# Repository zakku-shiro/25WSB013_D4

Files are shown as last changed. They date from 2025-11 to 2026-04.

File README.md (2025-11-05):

# project-pied-piper

This project is for the 25WSB013 - Project Design and Management module at Loughborough University, tackling specifically the "Pied Piper" challenge.

## Useful Links

### [Generic Project Information](https://learn.lboro.ac.uk/mod/forum/discuss.php?d=498549)

### [Pied Piper Specific Information](https://learn.lboro.ac.uk/mod/forum/discuss.php?d=498557)

### [RobotShop Rover Link](https://uk.robotshop.com/products/dfrobotshop-rover-tracked-robot-basic-kit)

### [Markdown Guide](https://www.markdownguide.org/basic-syntax/)

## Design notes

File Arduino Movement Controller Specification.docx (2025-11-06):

# Arduino Movement Controller Specification

# Important Definitions and Values

## Servo Motor Pinouts

PIN_MOTOR_1_SPEED (0x06)

Type: ANALOGUE

Values: 0-255, (0x00-0xFF)

Functionality: Controls the speed of the leftmost motor, with 0 being stationary and 255 being full speed.

PIN_MOTOR_1_DIRECTION (0x08)

Type: DIGITAL

Values: LOW|HIGH, (0|1)

Functionality: Controls the direction of the leftmost motor, with LOW being forward and HIGH being reverse.

PIN_MOTOR_2_SPEED (0x05)

Type: ANALOGUE

Values: 0-255, (0x00-0xFF)

Functionality: Controls the speed of the leftmost motor, with 0 being stationary and 255 being full speed.

PIN_MOTOR_2_DIRECTION (0x07)

Type: DIGITAL

Values: LOW|HIGH, (0|1)

Functionality: Controls the direction of the leftmost motor, with LOW being forward and HIGH being reverse.

## Helper Values

MOTOR_FORWARD (0x00, 0)

MOTOR_REVERSE (0x01, 1)

MOTOR_OFF_SPEED (0x00, 0)

MOTOR_MIN_SPEED (0x01, 1)

MOTOR_HALF_SPEED (0x7F, 127)

MOTOR_MAX_SPEED (0xFF, 255)

# Functions and Uses

## `moveForward`

## `moveReverse`

## `turnLeft`

## `turnRight`

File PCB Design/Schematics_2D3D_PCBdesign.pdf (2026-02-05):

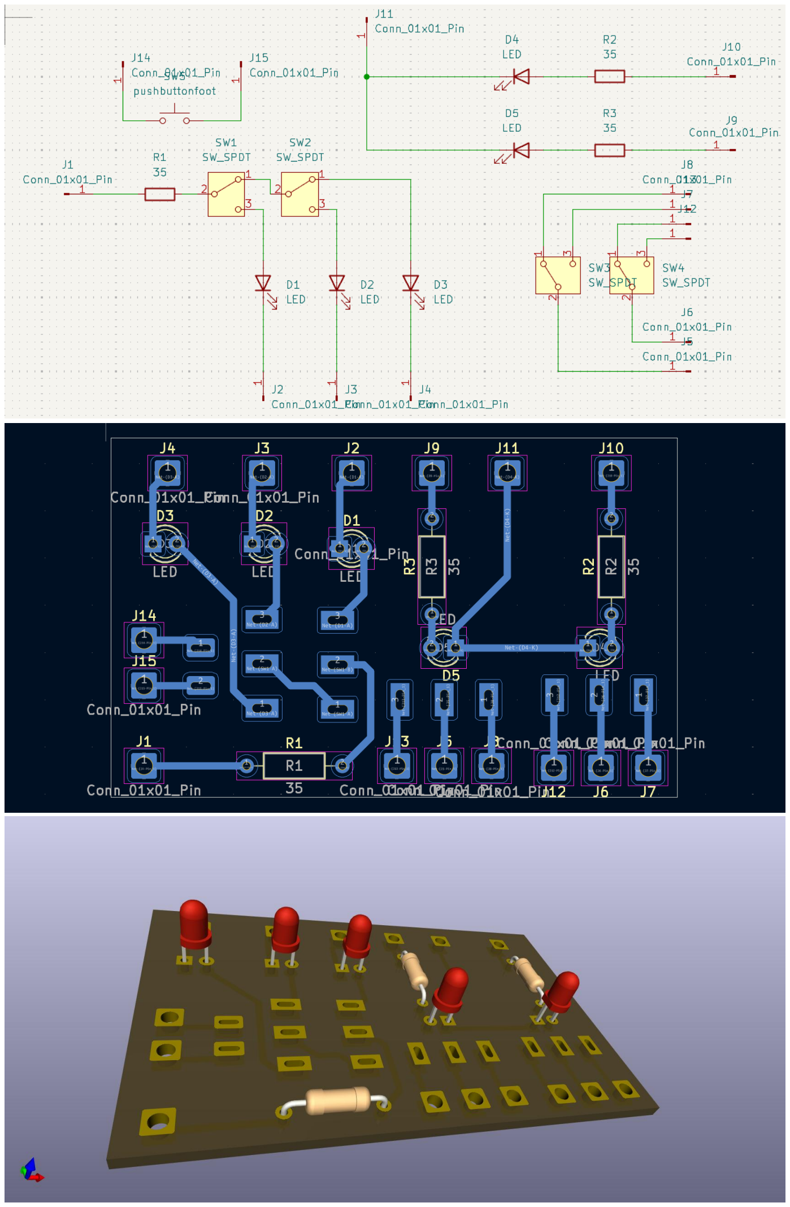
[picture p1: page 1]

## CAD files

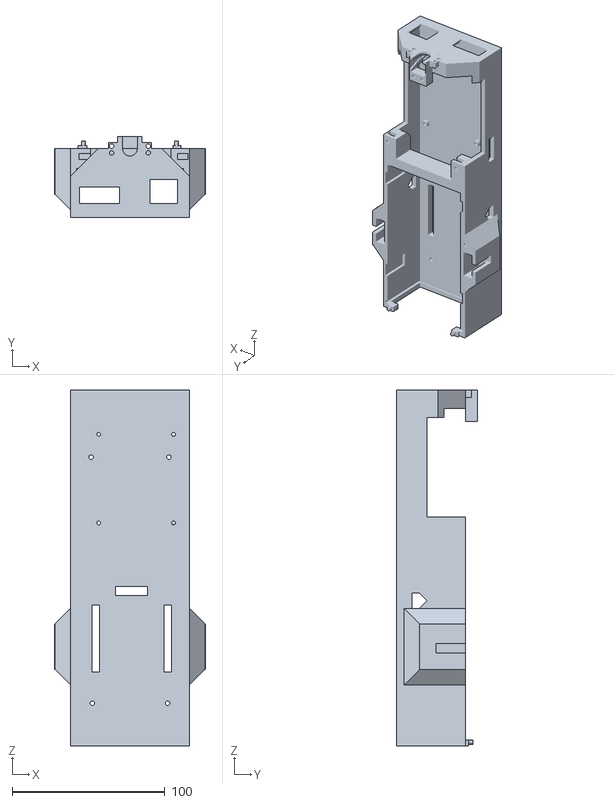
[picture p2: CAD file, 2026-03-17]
3d models and prints/main body new.stl
99.0 x 53.0 x 233.0

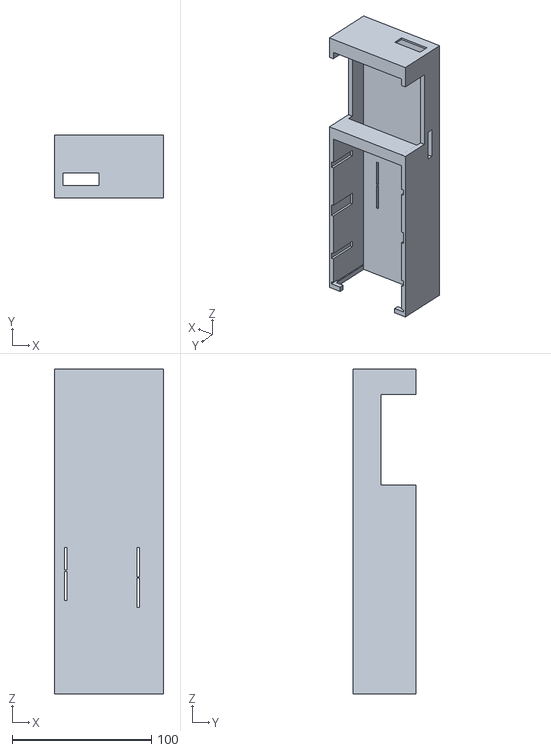
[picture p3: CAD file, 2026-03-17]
3d models and prints/main body.stl
78.0 x 45.0 x 233.0

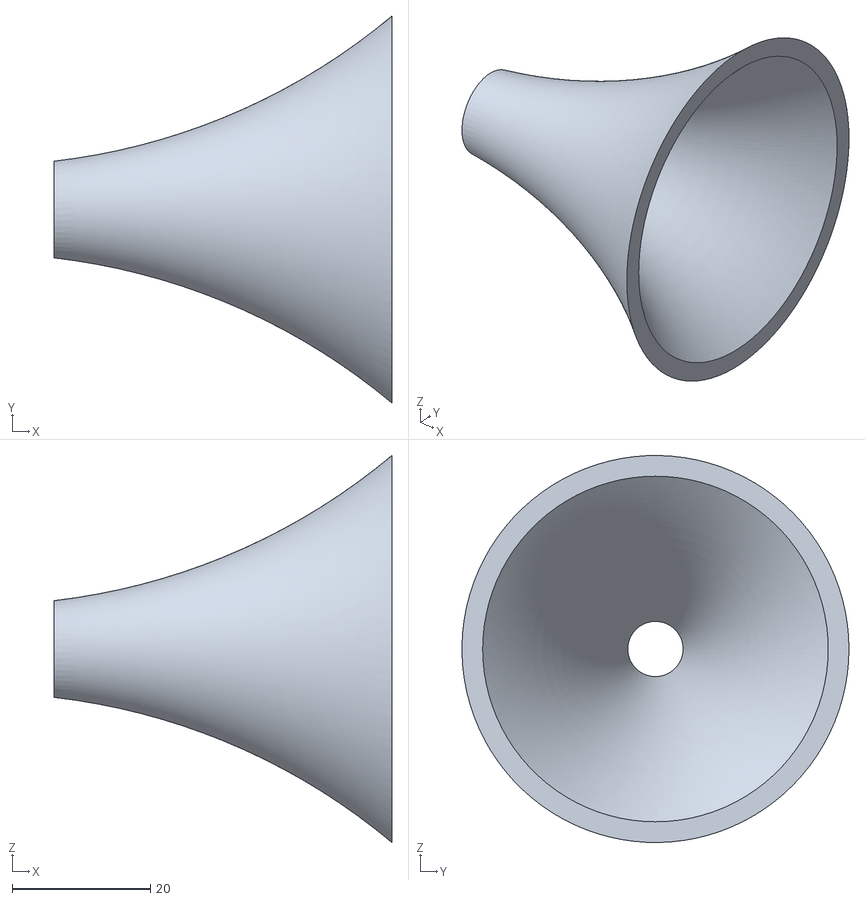
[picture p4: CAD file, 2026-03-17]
3d models and prints/Mic cone exp3.stl
48.9 x 56.0 x 56.0

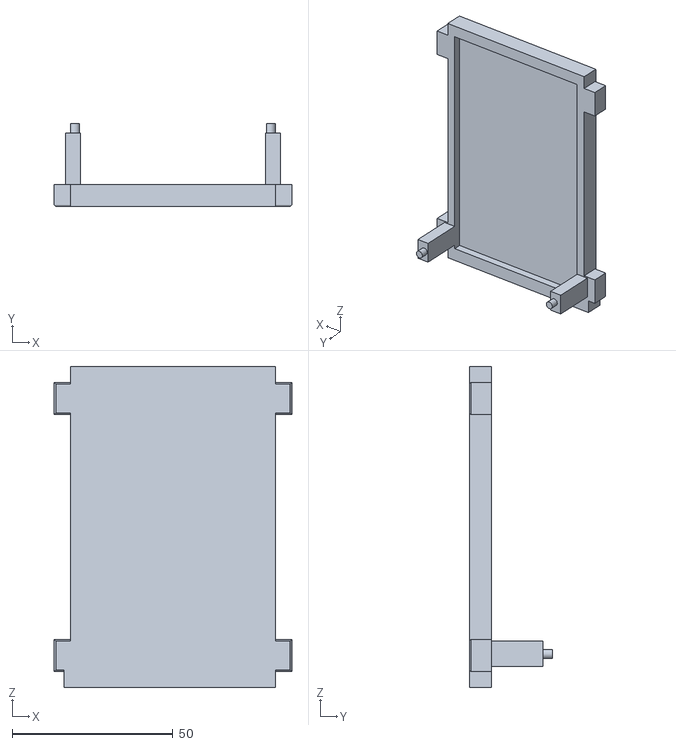
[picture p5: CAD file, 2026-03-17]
3d models and prints/battery mounting.stl
74.0 x 26.0 x 100.0

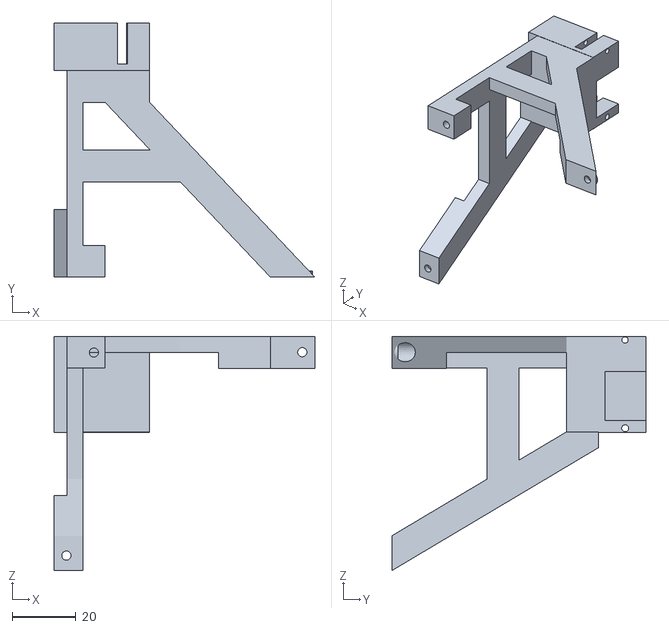
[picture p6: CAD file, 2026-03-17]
3d models and prints/cam stand.stl
82.1 x 80.0 x 73.7

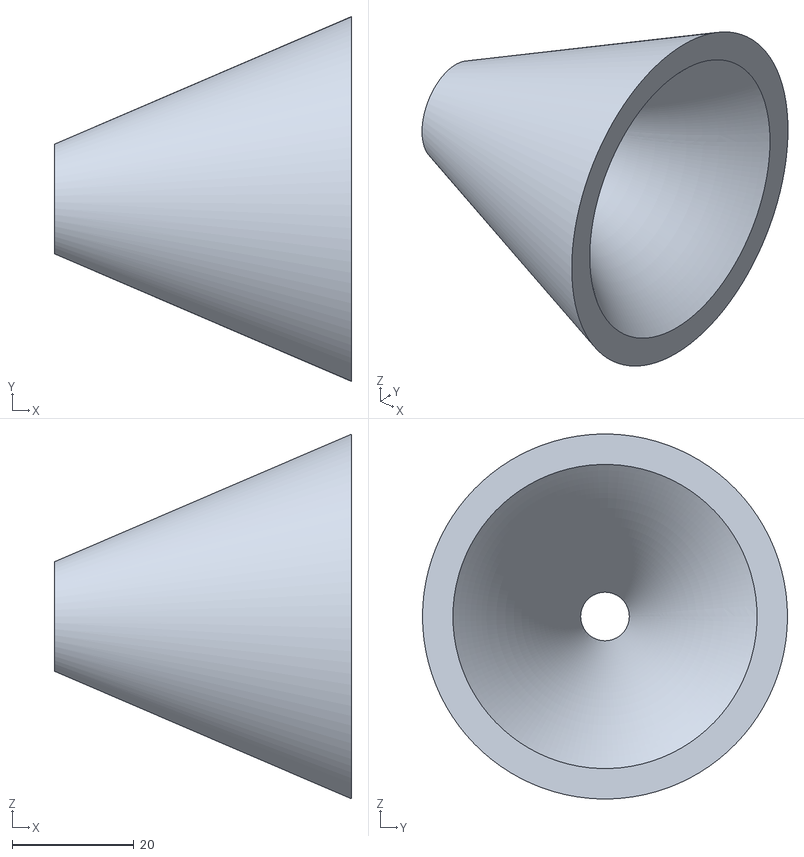
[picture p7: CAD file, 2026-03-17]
3d models and prints/Mic cone exp2.stl
48.9 x 60.0 x 60.0

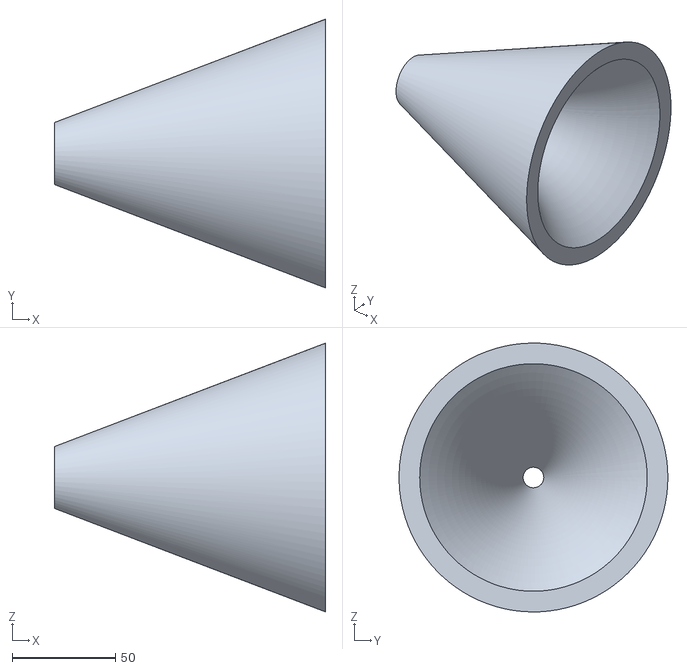
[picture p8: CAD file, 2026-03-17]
3d models and prints/Mic cone exp1.stl
131.0 x 130.0 x 130.0

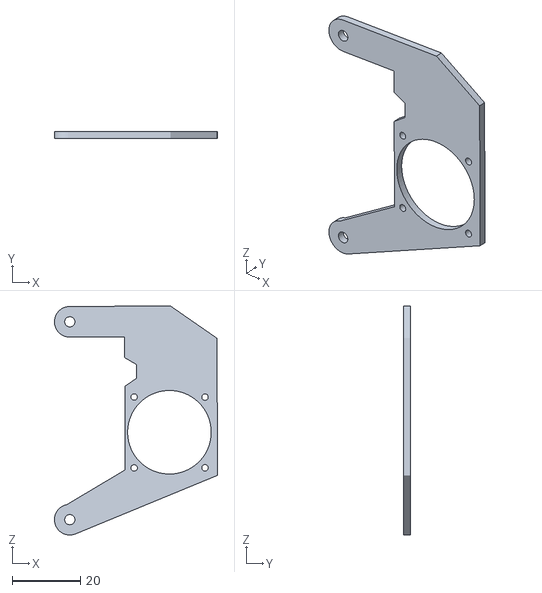
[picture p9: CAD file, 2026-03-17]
3d models and prints/fan mount.stl
47.8 x 2.00 x 67.1

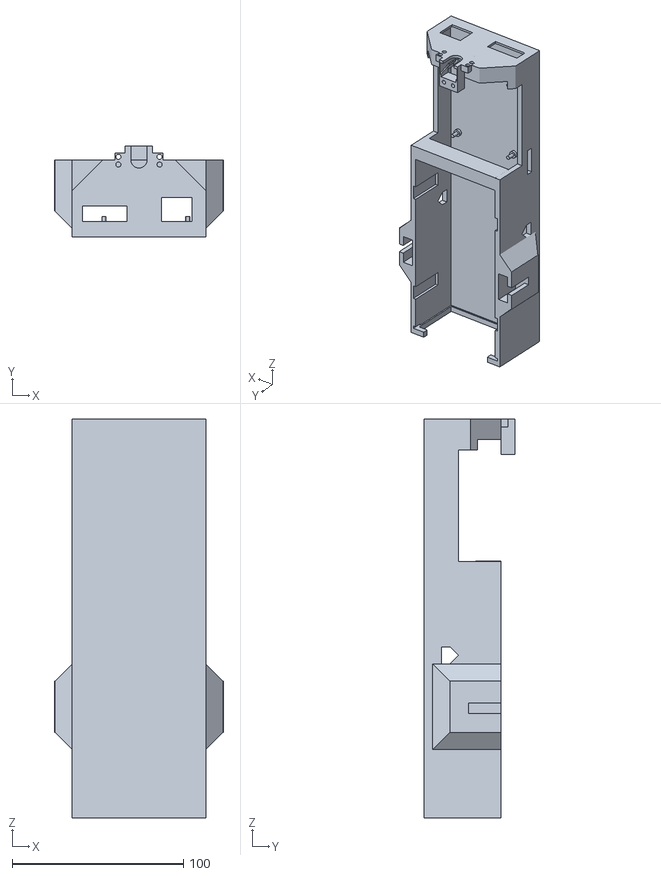
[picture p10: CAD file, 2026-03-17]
3d models and prints/body w front mic housing.stl
99.0 x 53.0 x 233.0

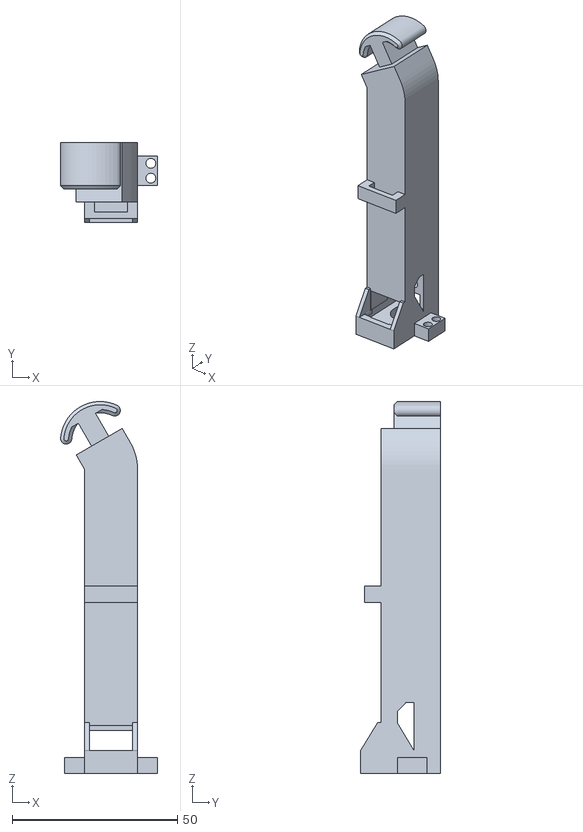
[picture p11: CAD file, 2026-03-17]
3d models and prints/mic arm.stl
29.3 x 24.1 x 112.5

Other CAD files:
3d models and prints/main body + fan mount.gcode.3mf
3d models and prints/main body.gcode.3mf
3d models and prints/tractric cone w attachment.gcode.3mf
3d models and prints/mic cone 1.gcode.3mf
3d models and prints/Join test.gcode.3mf
3d models and prints/camera bits.gcode.3mf
3d models and prints/Tractrix cone1.gcode.3mf
3d models and prints/pcb cover plate.gcode.3mf
3d models and prints/Mic cone exp3.gcode.3mf
3d models and prints/Tractrix cone1.stl
3d models and prints/battery mount.gcode.3mf
3d models and prints/cam mount.stl
3d models and prints/cam stand.gcode.3mf
3d models and prints/joint test1.stl
3d models and prints/joint test2.stl
3d models and prints/main body (2).stl
3d models and prints/mic arm (2).stl
3d models and prints/mic arm and cone1.gcode.3mf
3d models and prints/mic arm and cone2.gcode.3mf
3d models and prints/mic arm.gcode.3mf
3d models and prints/mic cone 1.3mf
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

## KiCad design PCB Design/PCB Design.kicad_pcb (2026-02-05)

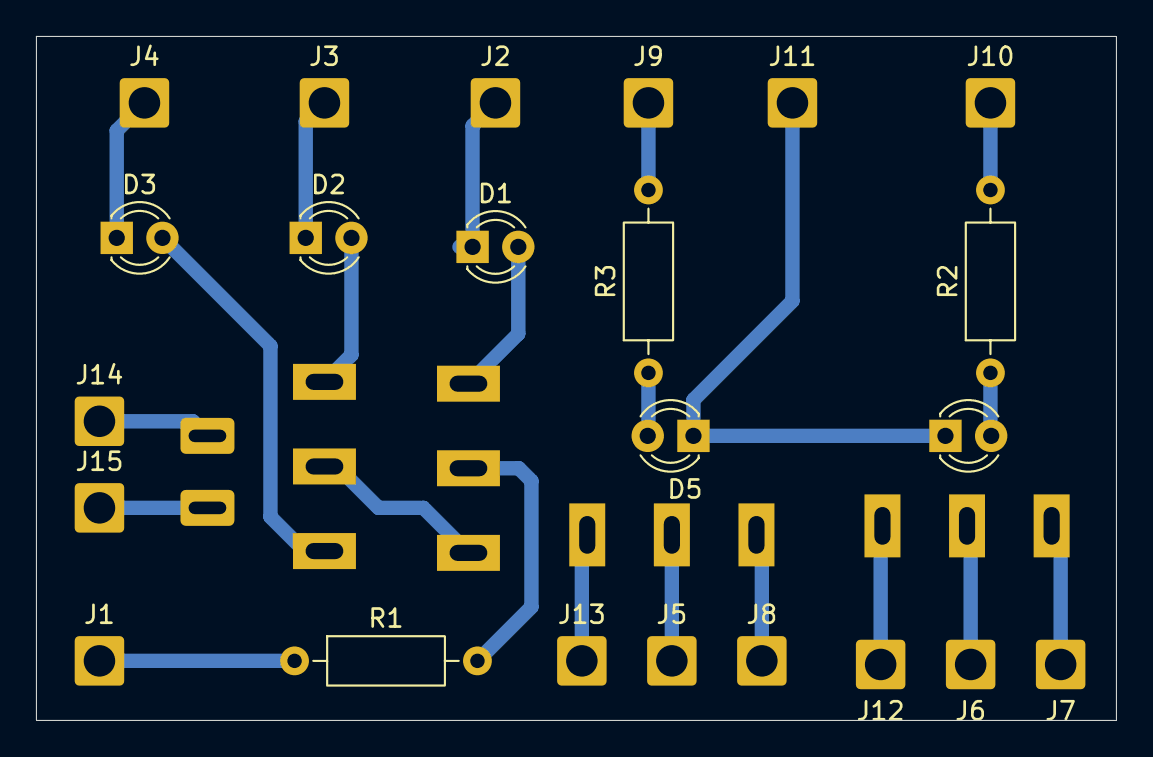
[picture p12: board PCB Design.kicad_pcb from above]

Board: 2 copper layers, 60.0 x 38.0 mm, 28 parts (0 on the bottom side), 22 nets.

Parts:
D1, D2, D3, D4, D5: LED; LED_D3.0mm
J1, J2, J3, J4, J5, J6, J7, J8, J9, J10, J11, J12, J13, J14, J15: Conn_01x01_Pin; SolderWire-1sqmm_1x01_D1.4mm_OD2.7mm
R1, R2, R3: 35; R_Axial_DIN0207_L6.3mm_D2.5mm_P10.16mm_Horizontal
SW1, SW2, SW3, SW4: SW_SPDT
SW5: pushbuttonfoot; Untitled

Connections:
unnamed: D1.2 (A), SW1.3 (C)
unnamed: D1.1 (K), J2.1
unnamed: D2.2 (A), SW2.3 (C)
unnamed: D2.1 (K), J3.1
unnamed: D3.2 (A), SW2.1 (A)
unnamed: D3.1 (K), J4.1
unnamed: D4.2 (A), R2.1
unnamed: D4.1 (K), D5.1 (K), J11.1
unnamed: D5.2 (A), R3.1
unnamed: J1.1, R1.1
unnamed: J5.1, SW3.2 (B)
unnamed: J6.1, SW4.2 (B)
unnamed: J7.1, SW4.1 (A)
unnamed: J8.1, SW3.1 (A)
unnamed: J9.1, R3.2
unnamed: J10.1, R2.2
unnamed: J12.1, SW4.3 (C)
unnamed: J13.1, SW3.3 (C)
unnamed: J14.1, SW5.1
unnamed: J15.1, SW5.2
unnamed: SW1.1 (A), SW2.2 (B)
unnamed: R1.2, SW1.2 (B)

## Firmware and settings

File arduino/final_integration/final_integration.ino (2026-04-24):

// Movement Definitions
#define PIN_MOTOR_1_SPEED 0x06
#define PIN_MOTOR_1_DIRECTION 0x08
#define PIN_MOTOR_2_SPEED 0x05
#define PIN_MOTOR_2_DIRECTION 0x07
// US Sensor Defs
#define US_TRIG_PIN 0x09
#define US_ECHO_PIN 0x0A
#define US_SEND_RATE_MS 250

#define MOTOR_FORWARD LOW
#define MOTOR_REVERSE HIGH

#define MOTOR_MAX_SPEED 255

// Comms Definitions
#define BAUD_RATE 500000
#define SYNC1 0xBE
#define SYNC2 0xEF
#define PACKET_BUFFER_SIZE 32

#define MOVE_PACKET_LENGTH 4
#define LED_PACKET_LENGTH 2

// Control Pins
#define LED_DEMO_ENABLED 0x0B
#define LED_MODE_SELECT  0x0C
#define LED_STATUS 0x02
#define DEMO_ENABLED_SWITCH 0x03
#define MODE_SELECT_SWITCH 0x04

enum {
  SIG_PING = 0,
  SIG_ERROR,
  SIG_ACKNOWLEDGE,
  SIG_SOUND_DATA,
  SIG_LED_COMMAND,
  SIG_MOVE_COMMAND,
  SIG_ULTRASONIC_DATA,
  SIG_SWITCH_DATA
};
static bool g_HasBeenAcknowledged = false;

// Watchdog Configs
unsigned long g_lastCommandTime = 0;
#define COMMAND_TIMEOUT_MS 1000

// US Controls
unsigned long g_lastUltrasonicPacketTime = 0;

// LED Controls
enum {
  OFF = 0,
  ON,
  SLOW_BLINK,
  FAST_BLINK
};  // LED Modes
#define BLINKING_TIME 200

bool g_isOnboardLEDOn = false,
     g_isOnboardLEDBlinking = false,
     g_isStatusLEDOn = false;
unsigned long g_OnboardLEDTargetTime = 0,
              g_StatusLEDTargetTime = 0;
uint8_t g_CurrentStatusLEDMode = OFF;

void setLeftMotorSpeed(uint8_t speed) {
  analogWrite(PIN_MOTOR_1_SPEED, speed);
}

void setLeftMotorDirection(uint8_t direction) {
  digitalWrite(PIN_MOTOR_1_DIRECTION, direction);
}

void setRightMotorSpeed(uint8_t speed) {
  analogWrite(PIN_MOTOR_2_SPEED, speed);
}

void setRightMotorDirection(uint8_t direction) {
  digitalWrite(PIN_MOTOR_2_DIRECTION, direction);
}

float getDistanceCm() {
  digitalWrite(US_TRIG_PIN, LOW);
  delayMicroseconds(2);
  digitalWrite(US_TRIG_PIN, HIGH);
  delayMicroseconds(10);
  digitalWrite(US_TRIG_PIN, LOW);

  long duration = pulseIn(US_ECHO_PIN, HIGH, 15000);

  if (duration == 0) {
    return 0;
  }
  
  // Formula for distance
  float distance = duration * 0.0343 / 2.0;
  return distance;
}

/*
  Packet Format:
  | SYNC1 | SYNC2 | TYPE | LEN | PAYLOAD | CRC |
*/
void parseSerial() {
  static uint8_t decodeState = 0;
  static uint8_t msgType;
  static uint8_t length;
  static uint8_t buffer[PACKET_BUFFER_SIZE];
  static uint8_t index;
  static uint8_t crc;

  enum {
    WAIT_SYNC1,
    WAIT_SYNC2,
    WAIT_TYPE,
    WAIT_LEN,
    WAIT_PAYLOAD,
    WAIT_CRC
  };

  while (Serial.available()) {
    uint8_t incomingByte = Serial.read();

    switch (decodeState) {
      case WAIT_SYNC1:
        if (incomingByte == SYNC1) decodeState = WAIT_SYNC2;
        break;

      case WAIT_SYNC2:
        if (incomingByte == SYNC2) decodeState = WAIT_TYPE;
        else decodeState = WAIT_SYNC1;
        break;

      case WAIT_TYPE:
        msgType = incomingByte;
        crc = incomingByte;
        decodeState = WAIT_LEN;
        break;

      case WAIT_LEN:
          length = incomingByte;
          if (length > PACKET_BUFFER_SIZE) { 
            decodeState = WAIT_SYNC1; 
            break;
          }
          crc ^= incomingByte;
          index = 0;
          decodeState = (length == 0) ? WAIT_CRC : WAIT_PAYLOAD;
          break;

      case WAIT_PAYLOAD:
        buffer[index++] = incomingByte;
        crc ^= incomingByte;

        if (index >= length)
          decodeState = WAIT_CRC;
        break;

      case WAIT_CRC:
        if (crc == incomingByte)
          handlePacket(msgType, buffer, length);

        decodeState = WAIT_SYNC1;
        break;
    }
  }
}

void handlePacket(uint8_t msg_type, uint8_t *data, uint8_t length) {
  bool invalidPacketLength = false;
  // Update watchdog timer
  g_lastCommandTime = millis();

  switch (msg_type) {
    case SIG_PING:
      sendPacket(SIG_ACKNOWLEDGE, 0, 0);
      return;

    case SIG_ACKNOWLEDGE:
      g_HasBeenAcknowledged = true;
      return;

    case SIG_LED_COMMAND: {
      if (length != LED_PACKET_LENGTH) {
        invalidPacketLength = true;
        break;
      }

      uint8_t pinIndex = data[0];
      uint8_t newStatus = data[1];

      switch (pinIndex) {
        case LED_DEMO_ENABLED:
        case LED_MODE_SELECT:
          digitalWrite(pinIndex, (newStatus == ON) ? HIGH : LOW);
          break;
        case LED_STATUS:
          g_CurrentStatusLEDMode = newStatus;
          break;
        default:
          break;
      }
      break;
    }

    case SIG_MOVE_COMMAND: {
      if (length != MOVE_PACKET_LENGTH) {
        invalidPacketLength = true;
        break;
      }

      setLeftMotorDirection(data[0] ? MOTOR_REVERSE : MOTOR_FORWARD);
      setRightMotorDirection(data[2] ? MOTOR_REVERSE : MOTOR_FORWARD);
      setLeftMotorSpeed((uint8_t)data[1]);
      setRightMotorSpeed((uint8_t)data[3]);

      break;
    }

    default: {
      uint8_t err[3] = {5, msg_type, length};
      sendPacket(SIG_ERROR, (uint8_t*)&err, 3);
      return;
    }
  }

  if (invalidPacketLength) {
    uint8_t err = 1;
    sendPacket(SIG_ERROR, &err, 1);
  } else {
    sendPacket(SIG_ACKNOWLEDGE, 0, 0);
  }
}

/*
    Packet Sender
*/
void sendPacket(uint8_t msgType, uint8_t *payload, uint8_t length) {
  if (Serial.availableForWrite() < (length + 5))
    return;

  uint8_t crc = msgType ^ length;

  Serial.write(SYNC1);
  Serial.write(SYNC2);
  Serial.write(msgType);
  Serial.write(length);

  for (uint8_t i = 0; i < length; i++) {
    Serial.write(payload[i]);
    crc ^= payload[i];
  }

  Serial.write(crc);
}

#define MIC_COUNT 3 // number of analog inputs
volatile uint16_t anaValue[MIC_COUNT];  // to store results (10-bit ADC fits in uint16_t)
volatile bool isFrameReady = false;

// ADC Interrupt Service Routine - fires when a conversion is complete
ISR(ADC_vect) {
  static uint8_t i = 0;

  anaValue[i] = ADC;
  i++;

  if (i >= MIC_COUNT) {
    i = 0;
    isFrameReady = true;
  }

  ADMUX = 0x40 | i;
  ADCSRA |= (1 << ADSC);
}

void setup() {
  pinMode(PIN_MOTOR_1_SPEED, OUTPUT);
  pinMode(PIN_MOTOR_1_DIRECTION, OUTPUT);
  pinMode(PIN_MOTOR_2_SPEED, OUTPUT);
  pinMode(PIN_MOTOR_2_DIRECTION, OUTPUT);
  pinMode(US_TRIG_PIN, OUTPUT);
  pinMode(US_ECHO_PIN, INPUT);
  pinMode(LED_BUILTIN, OUTPUT);
  pinMode(LED_MODE_SELECT, OUTPUT);
  pinMode(LED_DEMO_ENABLED, OUTPUT);
  pinMode(LED_STATUS, OUTPUT);
  pinMode(DEMO_ENABLED_SWITCH, INPUT_PULLUP);
  pinMode(MODE_SELECT_SWITCH, INPUT_PULLUP);

  // Zero Movement
  setLeftMotorSpeed(0);
  setRightMotorSpeed(0);
  
  /* Sound Setup*/
  // ADMUX: Set the reference voltage (AVCC) and select the first input A0 (0)
  ADMUX = 0x40; //| 0;

  ADCSRA |= (1 << ADIE);  //enable ADC Interrupt (ADIE)
  ADCSRA |= (1 << ADEN);  // enable ADC (ADEN)
  ADCSRA |= (1 << ADSC);  // start the first ADC conversion (ADSC)

  Serial.begin(BAUD_RATE);
  uint8_t counter = 0;
  while (!Serial) {
    digitalWrite(LED_BUILTIN, counter++ % 2);
  }

  // Read Switch States
  uint8_t switchStates[2] = {digitalRead(DEMO_ENABLED_SWITCH), digitalRead(MODE_SELECT_SWITCH)};
  sendPacket(SIG_SWITCH_DATA, (uint8_t*)&switchStates, 2);
  digitalWrite(LED_DEMO_ENABLED, switchStates[0]);
  digitalWrite(LED_MODE_SELECT, switchStates[1]);

  while (!g_HasBeenAcknowledged) {
    parseSerial();
  }
}

void loop() {
  parseSerial();

  // Watchdog safety stop
  if (millis() - g_lastCommandTime > COMMAND_TIMEOUT_MS && g_lastCommandTime != 0) {
    setLeftMotorSpeed(0);
    setRightMotorSpeed(0);
    setLeftMotorDirection(MOTOR_FORWARD);
    setRightMotorDirection(MOTOR_FORWARD);
  }

  // Ultrasonic Data Sending
  if (millis() - g_lastUltrasonicPacketTime > US_SEND_RATE_MS) {
    float distance = getDistanceCm();
    sendPacket(SIG_ULTRASONIC_DATA, (uint8_t*)&distance, sizeof(float));
    g_lastUltrasonicPacketTime = millis();
  }

  // Microphone Data Sending
  uint8_t packed_mic_data[4];
  if (isFrameReady) {
    isFrameReady = false;
    //removes end 2 of mic 1
    packed_mic_data[0] = (anaValue[0] >> 2) & 0xFF;
    //last 2 values of m1 shifted left 6, removes end half of m2
    packed_mic_data[1] = ((anaValue[0] & 0x03) << 6) | ((anaValue[1] >> 4) & 0x3F);
    //moves end half of m2 4 bits left, only keeps first 2 bits of m3 as last 2 bits
    packed_mic_data[2] = ((anaValue[1] & 0x0F) << 4) | ((anaValue[2] >> 6) & 0x0F);
    //rest of m3
    packed_mic_data[3] = (anaValue[2] & 0x3F);

    sendPacket(SIG_SOUND_DATA, (uint8_t*)&packed_mic_data, 4);
  }

  // LED Blink Handler - Horrific
  if (g_isOnboardLEDBlinking) {
    if (millis() >= g_OnboardLEDTargetTime) {
      if (g_isOnboardLEDOn) {
        digitalWrite(LED_BUILTIN, LOW);
        g_isOnboardLEDOn = false;
      } else {
        digitalWrite(LED_BUILTIN, HIGH);
        g_isOnboardLEDOn = true;
      }
      g_OnboardLEDTargetTime = millis() + BLINKING_TIME;
    }
  }

  switch (g_CurrentStatusLEDMode) {
    default:
    case OFF:
      if (g_isStatusLEDOn != false) {
        digitalWrite(LED_STATUS, LOW);
        g_isStatusLEDOn = false;
      }
      break;
    case ON:
      if (g_isStatusLEDOn != true) {
        digitalWrite(LED_STATUS, HIGH);
        g_isStatusLEDOn = true;
      }
      break;
    case SLOW_BLINK:
      if (millis() >= g_StatusLEDTargetTime) {
        g_isStatusLEDOn = !g_isStatusLEDOn;
        digitalWrite(LED_STATUS, g_isStatusLEDOn);
        g_StatusLEDTargetTime = millis() + BLINKING_TIME;
      }
      break;
    case FAST_BLINK:
      if (millis() >= g_StatusLEDTargetTime) {
        g_isStatusLEDOn = !g_isStatusLEDOn;
        digitalWrite(LED_STATUS, g_isStatusLEDOn);
        g_StatusLEDTargetTime = millis() + BLINKING_TIME / 2;
      }
      break;
  }
}

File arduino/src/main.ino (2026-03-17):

#define PIN_MOTOR_1_SPEED 0x06  // ANALOGUE,  0-255,    Left Motor Speed Control
#define PIN_MOTOR_1_DIRECTION \
  0x08  // DIGITAL,   LOW/HIGH, Left Motor Direction Control
#define PIN_MOTOR_2_SPEED \
  0x05  // ANALOGUE,  0-255,    Right Motor Speed Control
#define PIN_MOTOR_2_DIRECTION \
  0x07  // DIGITAL, LOW/HIGH, Right Motor Direction Control
#define MOTOR_FORWARD LOW
#define MOTOR_REVERSE HIGH
#define MOTOR_OFF_SPEED 0
#define MOTOR_MIN_SPEED 1
#define MOTOR_HALF_SPEED 127
#define MOTOR_MAX_SPEED 255
#define BAUD_RATE 500000

#include <Arduino.h>
#include <pins_arduino.h>
#include <stddef.h>

void setLeftMotorSpeed(uint8_t motor_speed) {
  Serial.print("Set Left Motor Speed: ");
  Serial.println(motor_speed);
  analogWrite(PIN_MOTOR_1_SPEED, motor_speed);
}

void setRightMotorSpeed(uint8_t motor_speed) {
  Serial.print("Set Right Motor Speed: ");
  Serial.println(motor_speed);
  analogWrite(PIN_MOTOR_2_SPEED, motor_speed);
}

void setMotorSpeed(uint8_t motor_speed) {
  setLeftMotorSpeed(motor_speed);
  setRightMotorSpeed(motor_speed);
}

void moveForward() {
  Serial.println("Change Direction: Forward");
  // Set both motors forward
  digitalWrite(PIN_MOTOR_1_DIRECTION, MOTOR_FORWARD);
  digitalWrite(PIN_MOTOR_2_DIRECTION, MOTOR_FORWARD);
}

void moveForward(size_t delay_ms) {
  moveForward();
  delay(delay_ms);
}

void moveReverse() {
  Serial.println("Change Direction: Reverse");
  // Set both motors in reverse
  digitalWrite(PIN_MOTOR_1_DIRECTION, MOTOR_REVERSE);
  digitalWrite(PIN_MOTOR_2_DIRECTION, MOTOR_REVERSE);
}

void moveReverse(size_t delay_ms) {
  moveReverse();
  delay(delay_ms);
}

void turnLeft() {
  Serial.println("Change Direction: Left");
  // Set motor directions
  digitalWrite(PIN_MOTOR_1_DIRECTION, MOTOR_REVERSE);
  digitalWrite(PIN_MOTOR_2_DIRECTION, MOTOR_FORWARD);
}

void turnLeft(size_t delay_ms) {
  turnLeft();
  delay(delay_ms);
}

void turnRight() {
  Serial.println("Change Direction: Right");
  // Set motor directions
  digitalWrite(PIN_MOTOR_1_DIRECTION, MOTOR_FORWARD);
  digitalWrite(PIN_MOTOR_2_DIRECTION, MOTOR_REVERSE);
}

void turnRight(size_t delay_ms) {
  turnRight();
  delay(delay_ms);
}

void stopMotors() {
  Serial.println("Stopped!");
  analogWrite(PIN_MOTOR_1_SPEED, MOTOR_OFF_SPEED);
  analogWrite(PIN_MOTOR_2_SPEED, MOTOR_OFF_SPEED);
}

void setup() {
  Serial.begin(BAUD_RATE);
  Serial.println("Serial Initialized");
  // GPIO Setup
  for (uint8_t i = 5; i <= 8; i++) {
    Serial.print("Set Pin #");
    Serial.print(i);
    Serial.println(": OUTPUT");
    pinMode(i, OUTPUT);
  }
  Serial.println("GPIO Initialized");

  setMotorSpeed(MOTOR_MAX_SPEED);
}

void loop() {
  turnRight(4000);
  turnLeft(4000);
  moveForward(1000);
  turnRight(1000);
  moveForward(5000);
  turnRight(1000);
  moveForward(5000);
  turnRight(1000);
  moveForward(10000);
  turnRight(1000);
  moveForward(5000);
  turnRight(1000);
  moveForward(5000);
  turnRight(1000);
  moveForward(1000);
  turnRight(2000);
}

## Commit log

2025-11-05 Add RobotRover sample code
2025-11-06 Create Platform IO Project for Arduino
2025-11-14 Initial Commits for PCB
    [PCB Design.kicad_pcb, PCB Design.kicad_sch]
2025-11-15 intial circuit implementation
    [PCB Design.kicad_sch]
2025-11-16 adjustements the PCB schematic
    [PCB Design.kicad_sch]
2025-11-16 adding contraints
    [PCBDesign.kicad_pcb]
2025-11-16 change in name to link the schematic and pcb platforms
    [PCB Design.kicad_sch, PCBDesign.kicad_pcb]
2025-11-16 intial pcb desin and testing of 3d model - some contraint voilations
    [PCB Design.kicad_pcb, PCB Design.kicad_sch]
2025-11-18 altered schematic and PCB layout for new SPDT switches
    [PCB Design.kicad_pcb, PCB Design.kicad_sch]
2025-11-19 demo code of functionality of the ultrasonic sensor with reference to rover behaviour
2025-11-21 adding footprint for the swithces
    [PCB Design.kicad_pcb, PCB Design.kicad_sch]
2025-11-21 completed main pcb design
    [PCB Design.kicad_pcb, PCB Design.kicad_sch]
2025-11-23 added Gerber files
    [PCB Design.kicad_pcb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]
2025-11-23 adding LED testing code to check resistor values
2025-11-23 integration of ultrasonic sensor with movement code
2025-12-03 moved to correct location
    [sound_data_collection.ino]
2025-12-03 made 3d prints folder
2025-12-03 Added files for finished ultrasonic housing
    [ultrasonic back.stl, ultrasonic front v2.gcode.3mf, ultrasonic front.stl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]
2025-12-09 alterations to pcb design
2026-02-18 Fix unpacking issue and boolean evals
    [main.py]
2026-02-25 adding the USS validation of the location of speaker and light
    [DisValDem.csv, DisValDem_excelgraph.csv]
2026-02-26 Update camera exposure settings
2026-03-04 Fix pi-camera auto-exposure and disable auto-white-balance
    [camera.py]
2026-03-04 additions to make USS sensor code work
2026-03-11 Added all files used for 3d printing(excluding fusion model files not exported)
    [Join test.gcode.3mf, Mic cone exp1.stl, Mic cone exp2.stl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]
2026-03-17 added double adc prescaler
2026-04-18 changes to the pcb
2026-04-24 subsystem-integration (#3)
    * Command line movement control
    * Command line movement control
    * Add .env support for serial port
    * Update to current working format of communications & control
    * Update to current working format of communications & control - Pi
    * Update to current working format of communications & control - Pi
    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
